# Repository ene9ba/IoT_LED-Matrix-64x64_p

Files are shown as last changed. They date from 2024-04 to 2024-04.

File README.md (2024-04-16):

# IoT_LED-Matrix-64x64_p
LED-Matrix Display driven by Raspi PICOW  Comchain: openHAB - mqtt - wifi - display develoed with platformio
**IoT RGB-Matrixdisplay to visualize temperatures from air ant HOT Tub via WiFi over MQTT to openHAB**
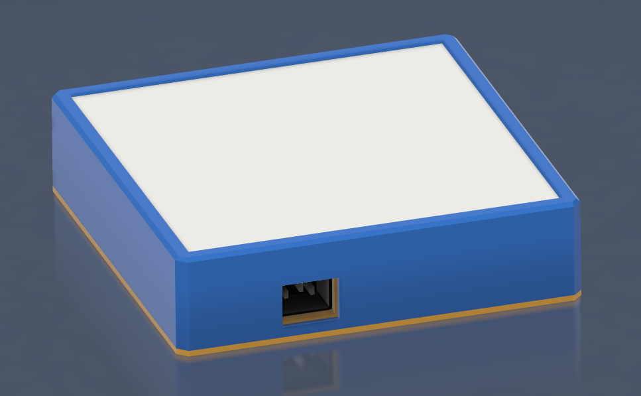
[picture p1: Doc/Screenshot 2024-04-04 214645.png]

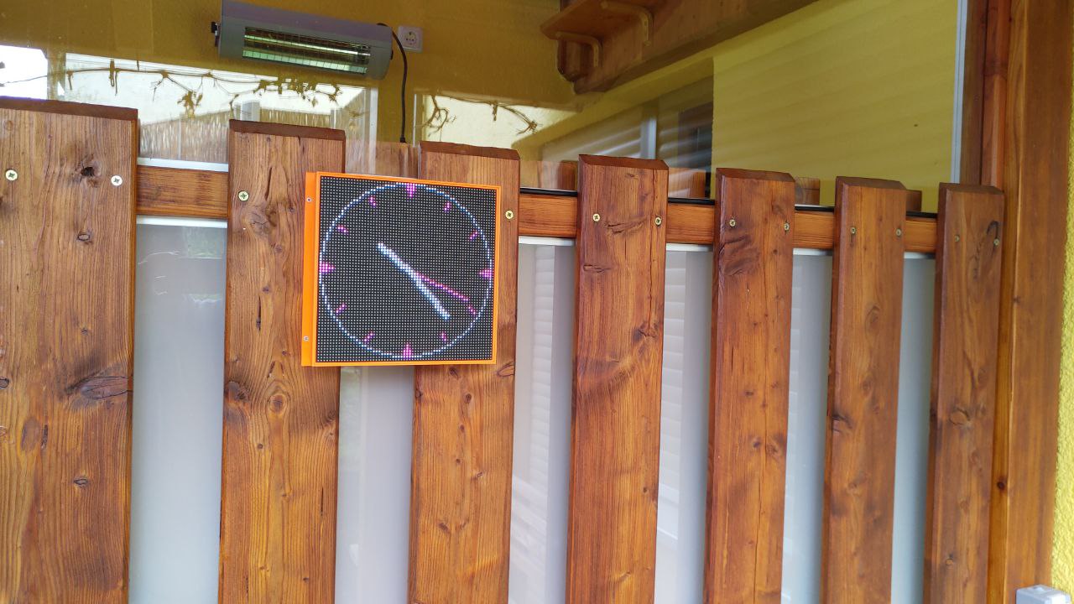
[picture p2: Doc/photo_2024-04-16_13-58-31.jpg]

# Goal of this project
To use a 64x64 RGB matrix display for visualisation of temperature, time and systemstate of my HotTub (whrilpool).
The picture should be absolute flickerree.

The project consits of three parts:

## Part 1: 
Hardwaredesign controller RP 2040 PICO W and powershifting 3.3 V to 5 V 
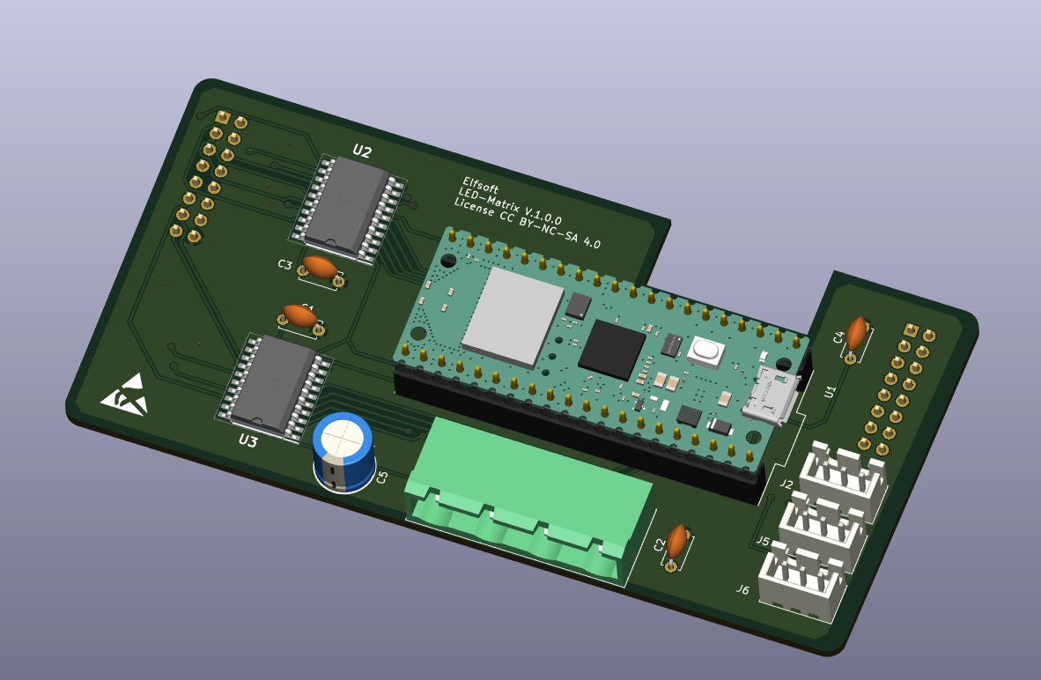
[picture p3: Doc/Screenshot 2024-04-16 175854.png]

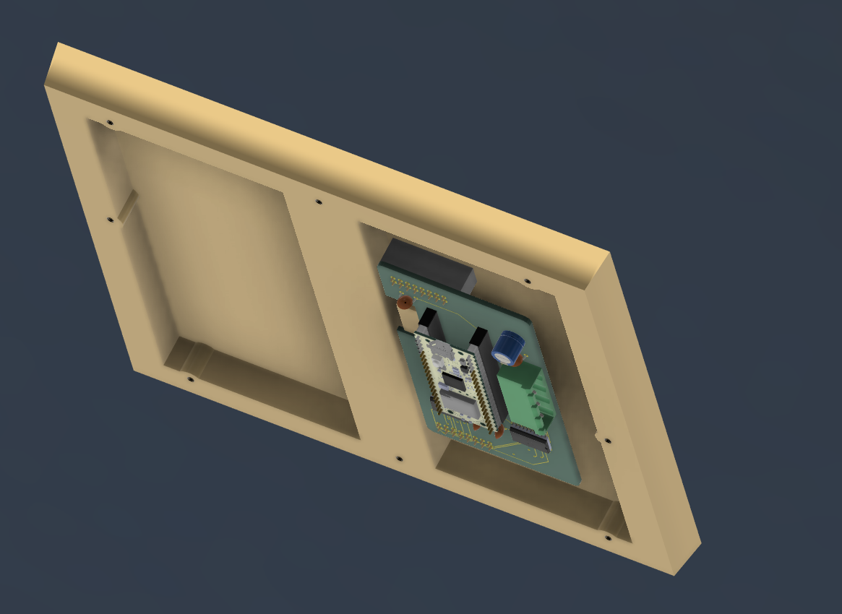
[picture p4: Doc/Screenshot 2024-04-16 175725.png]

## Part 2: 
Softwaredevelopment matrix control, connection to Wifi, connection to mqtt 

## Part 3: 3D Case design
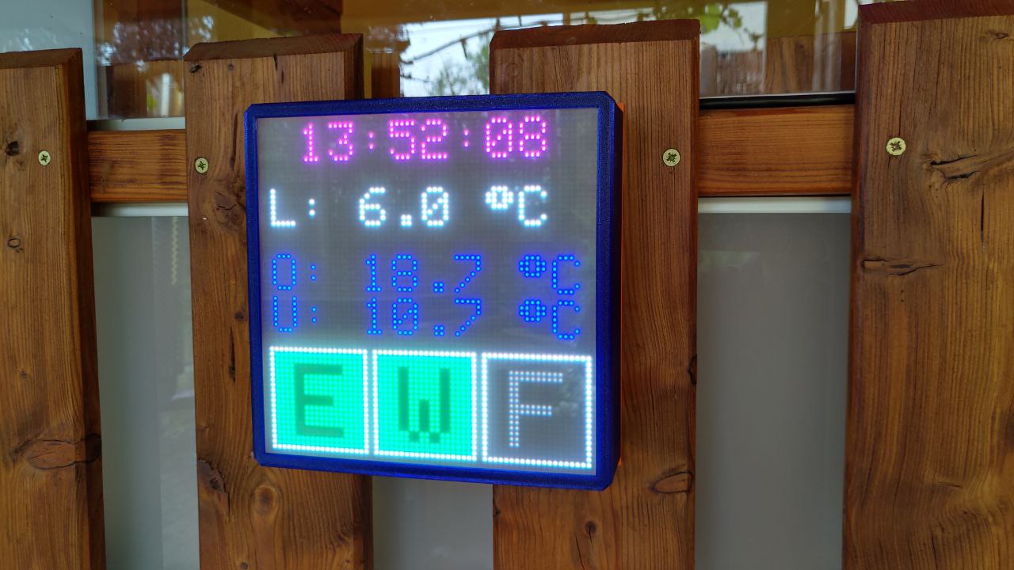
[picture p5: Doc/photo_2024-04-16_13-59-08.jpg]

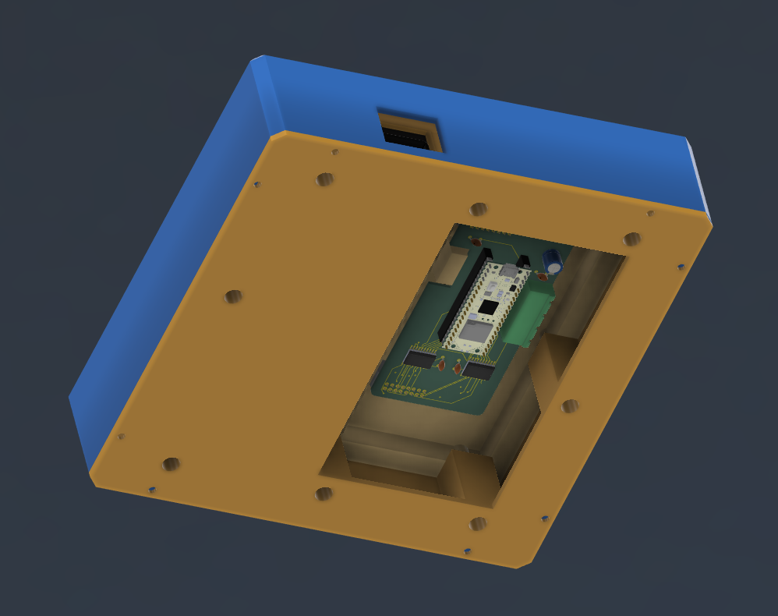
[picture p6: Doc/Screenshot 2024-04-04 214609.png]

## Info:
The LED-Panel is integrated in a self designed case with integrated power supply. Communication to SMART-Home runs via WiFi and MQTT to opnHAB.
The contoller I'm using is Raspberry Pi PICO RP2040 because it meets the requriements for WiFi and control the LED-panel **flickerfree** using the realtine state-machine on the chip.

The pcb will be pluged directly to the pins on the panel, there is no need for additional cabling.

Software ist developed with PlatformIO IDE.

I'm using displaytype RGB_LEF Joy-It. Most pinouts from other manaufactorers are the same, but have a look to the pcb pinout to be shure pining fits.

### Designfiles for the Case you can find on [thingeverese]() or [printables]().

### Credits and Acknowledgments
This project builds upon the work of the following contributors:

**pitschu:** For providing the initial groundwork and hardware interfacing for driving HUB75 LED Matrix panels with Raspberry Pi Pico's PIO

**Bodmer/Adafruit-GFX-Library:** For the core graphics library, enabling compatibility with Adafruit's GFX library and enhancing the display manipulation capabilities of the project.

**ClemensElflein:** For adapt the software to run on pico w without FREERTOS (works now with Arduino WifFi libraries)

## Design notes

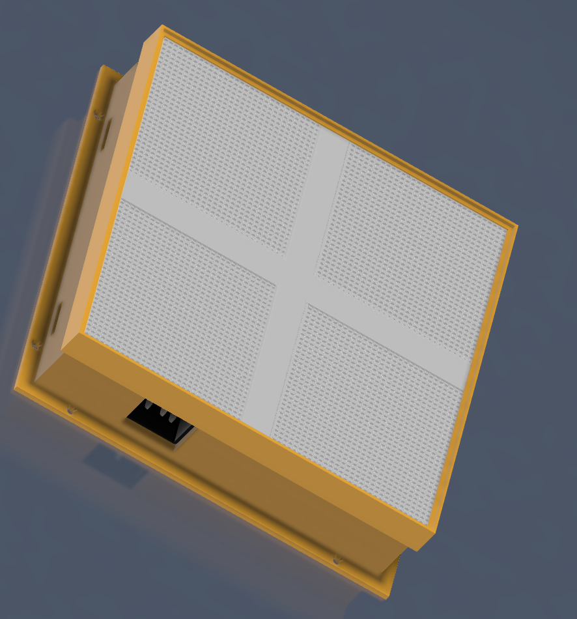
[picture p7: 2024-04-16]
Doc/Screenshot 2024-04-04 214305.png

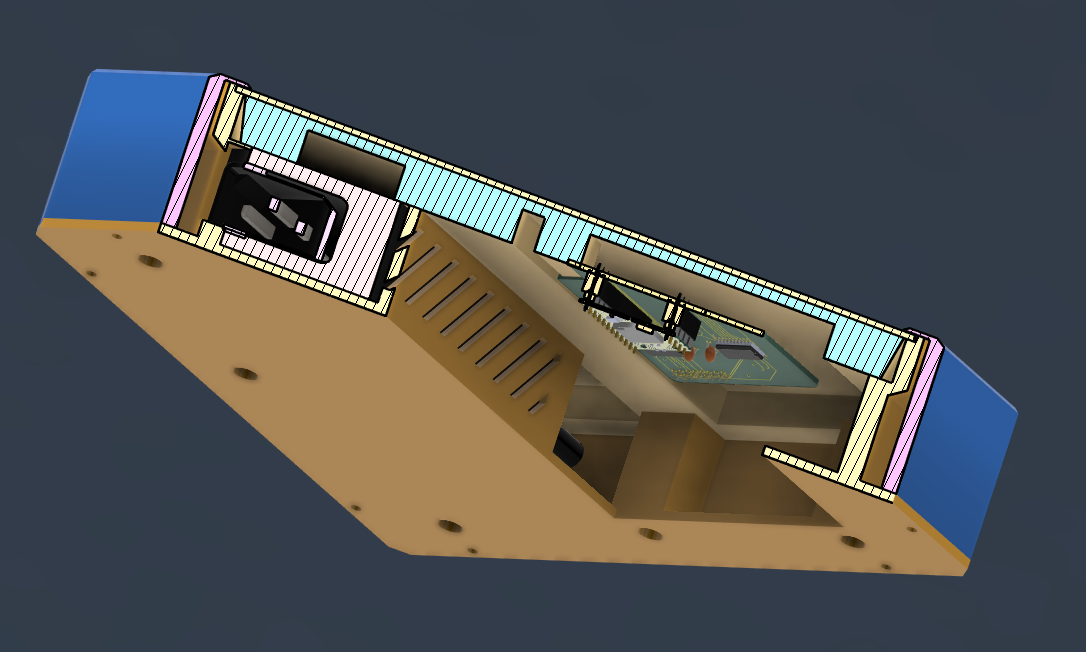
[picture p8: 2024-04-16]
Doc/Screenshot 2024-04-04 220111.png

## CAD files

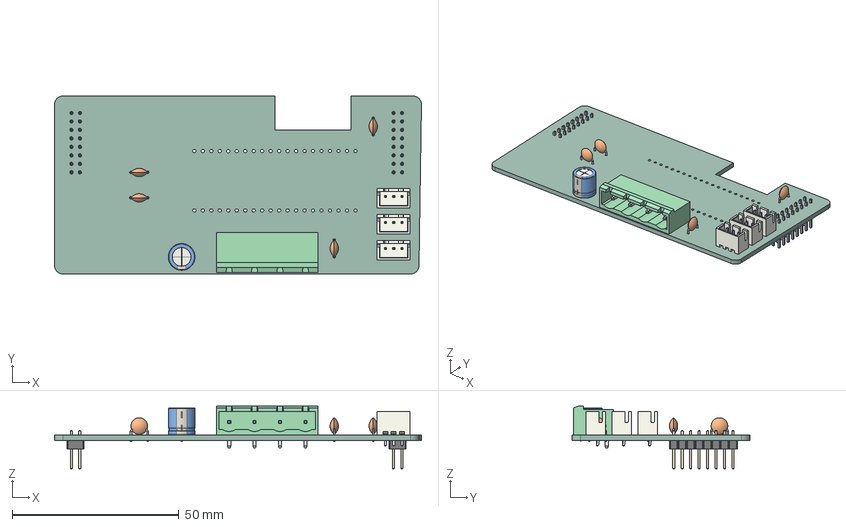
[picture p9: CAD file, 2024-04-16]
Hardware/LED-Matrix-driver.step
110.0 x 53.3 x 18.8 mm
C_Disc_D50mm_W25mm_P500mm x 4
GMSTBA_01x04_G_7_62mm
JST_B3B_XH_A x 3
CP_Radial_D80mm_P500mm
PinHeader_2x08_P254mm_Vertical x 2
_autosave-LED-Matrix-driver_PCB

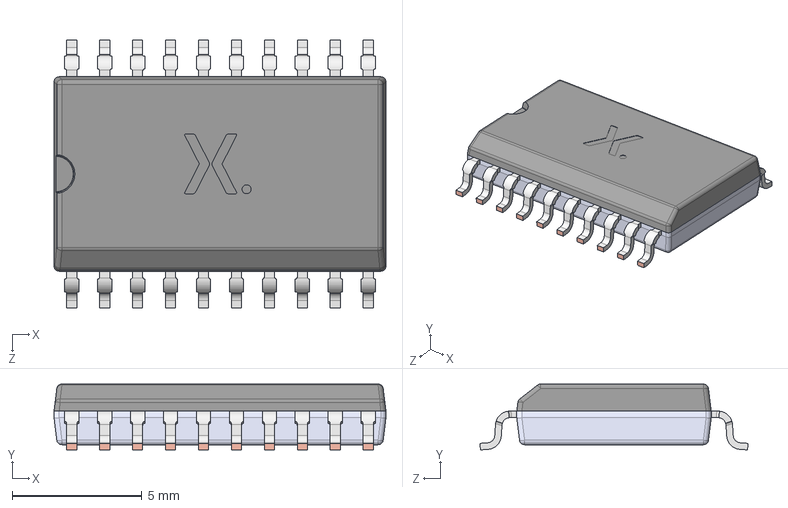
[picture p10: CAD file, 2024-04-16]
Hardware/3D/74HC245D-Q100J.stp
12.8 x 2.54 x 10.3 mm
SOT163 lower body
SOT163 upper body
SOT163-1 Lead

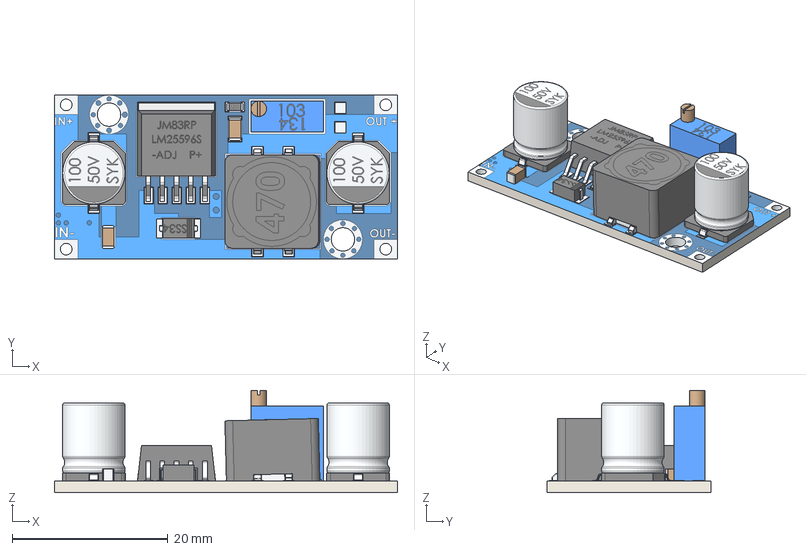
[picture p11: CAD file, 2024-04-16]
Hardware/3D/LM2596.step
44.0 x 21.0 x 13.1 mm

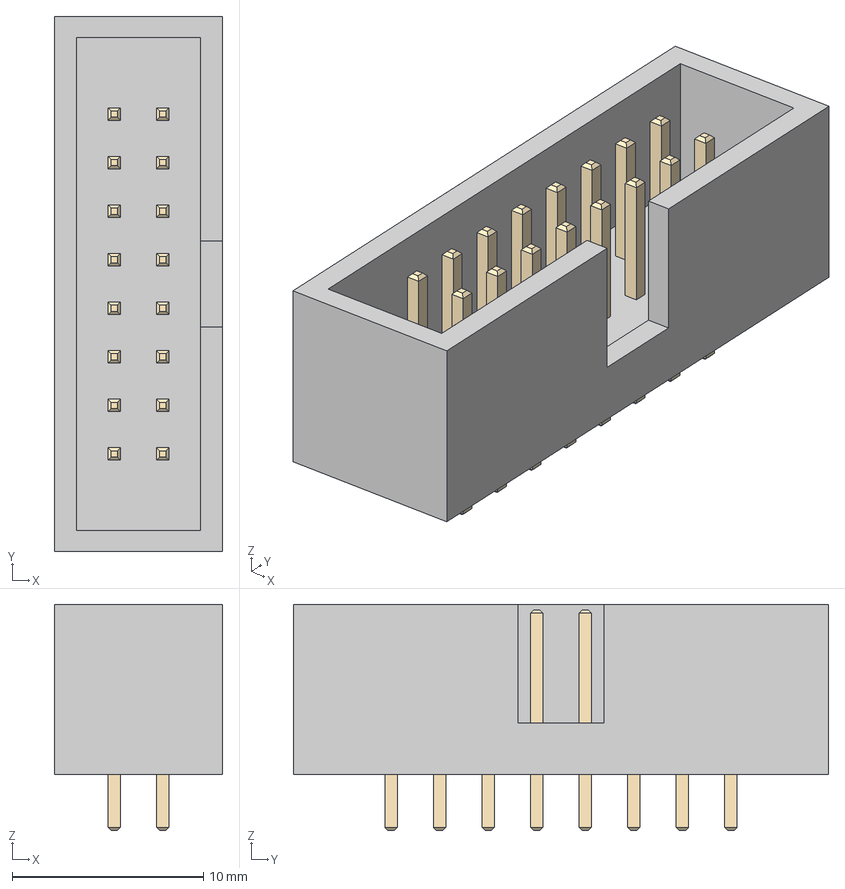
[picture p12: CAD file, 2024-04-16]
Hardware/3D/pinhead_2x8_shrouded.step
8.80 x 28.0 x 11.8 mm

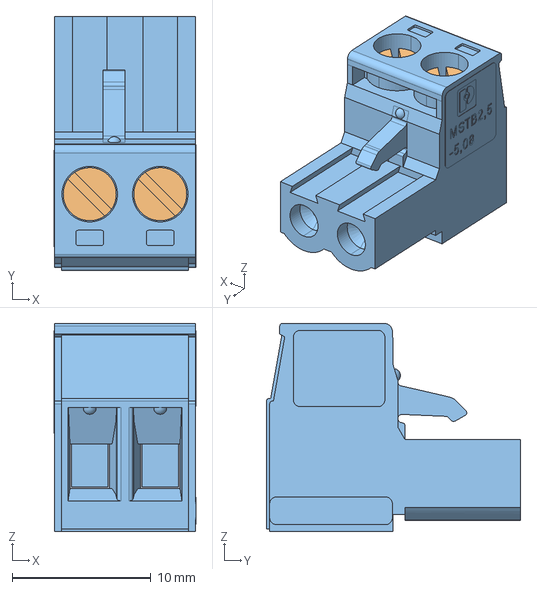
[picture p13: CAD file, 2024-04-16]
Hardware/3D/1757019.stp
10.2 x 18.3 x 15.0 mm

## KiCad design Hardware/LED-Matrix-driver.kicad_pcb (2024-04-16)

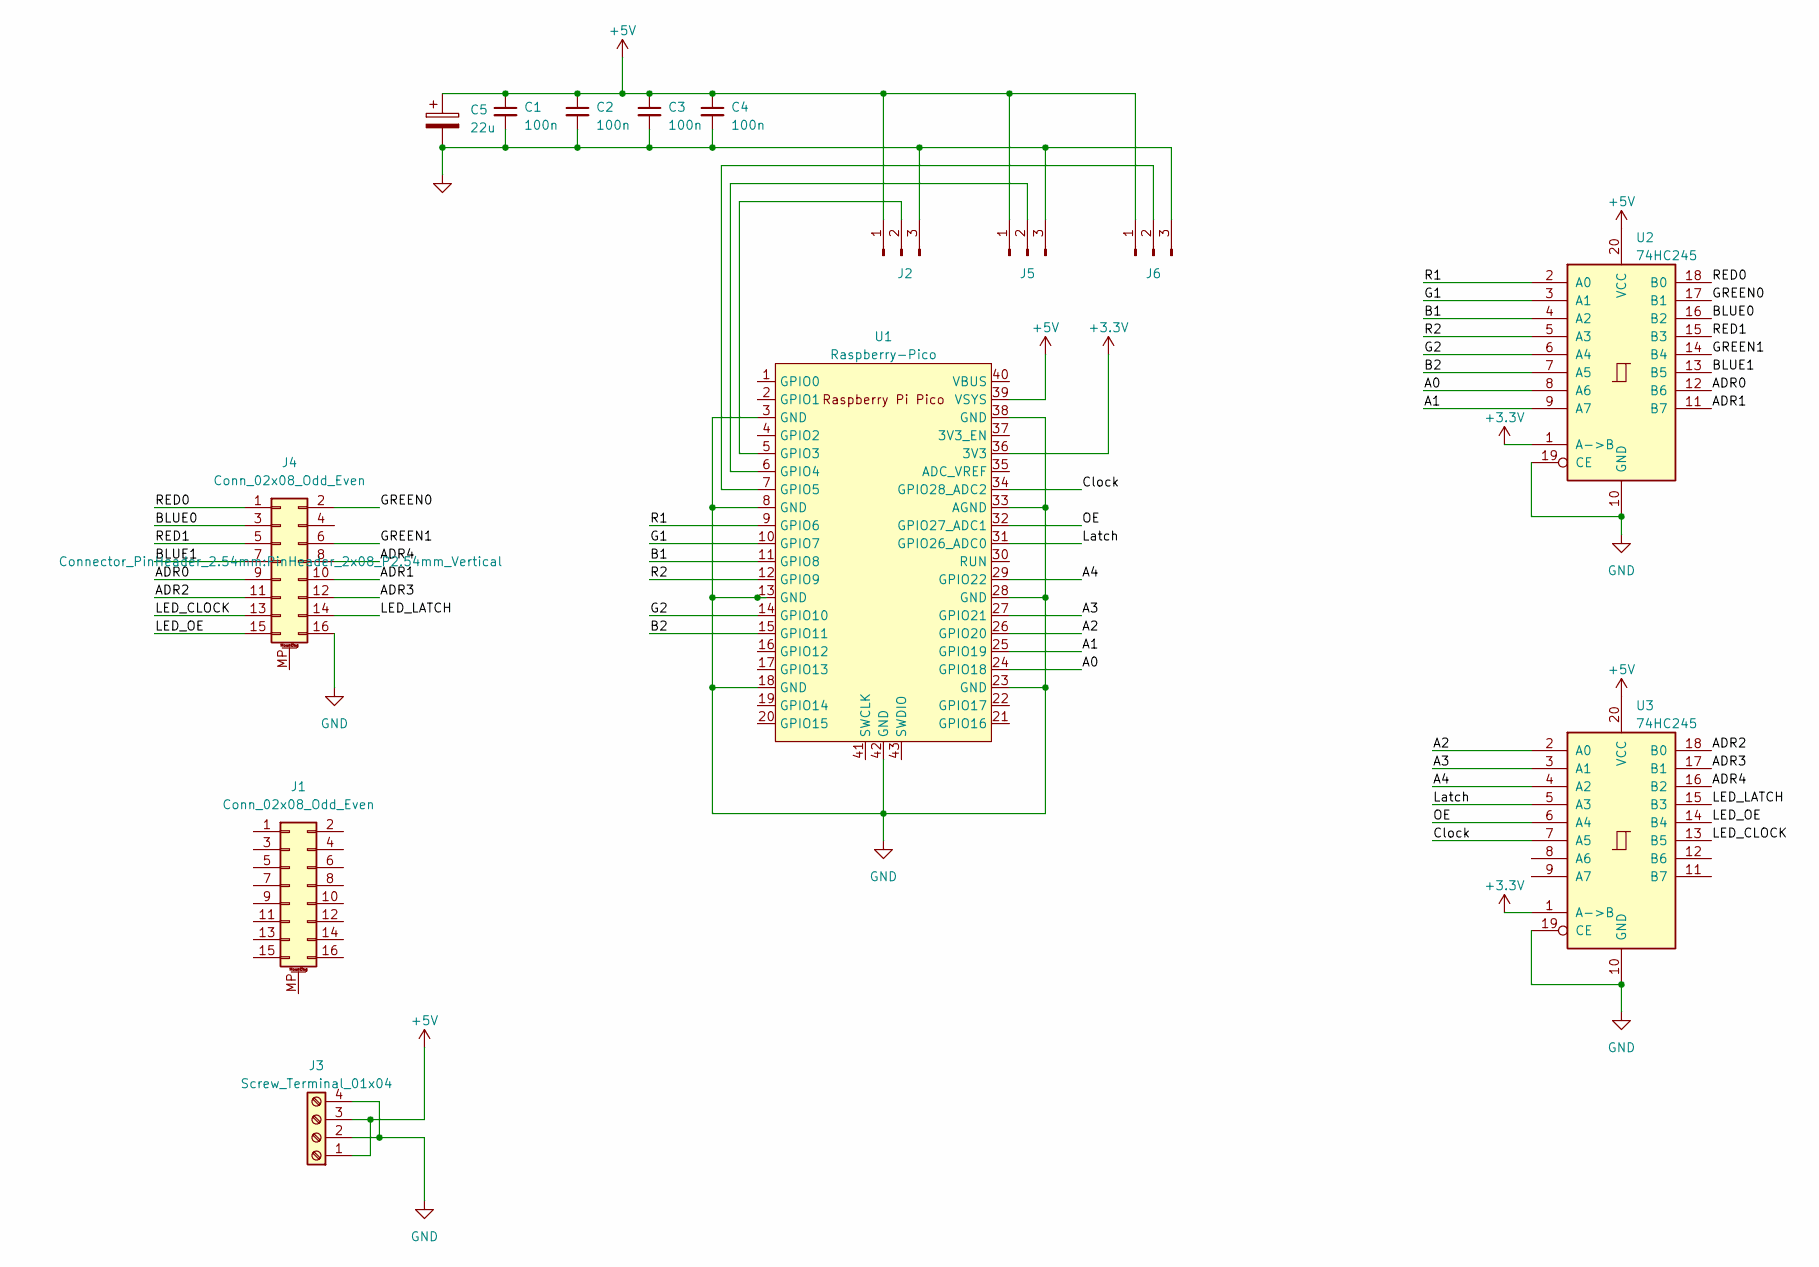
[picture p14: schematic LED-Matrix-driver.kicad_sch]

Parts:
C1, C2, C3, C4: 100n; C_Disc_D5.0mm_W2.5mm_P5.00mm
C5: 22u; CP_Radial_D8.0mm_P5.00mm
J1, J4: Conn_02x08_Odd_Even; PinHeader_2x08_P2.54mm_Vertical
J2, J5, J6: Conn_01x03_Pin; JST_XH_B3B-XH-A_1x03_P2.50mm_Vertical
J3: Screw_Terminal_01x04; PhoenixContact_GMSTBA_2,5_4-G-7,62_1x04_P7.62mm_Horizontal
U1: Raspberry-Pico; MODULE_SC0918
U2, U3: 74HC245; SOIC127P1032X265-20N

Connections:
+3.3V: U1.36 (3V3), U2.1 (A->B), U3.1 (A->B)
+5V: C1.1, C2.1, C3.1, C4.1, C5.1, J2.1, J3.1, J3.3, J5.1, J6.1, U1.39 (VSYS), U2.20 (VCC), U3.20 (VCC)
/A0: U1.24 (GPIO18), U2.8 (A6)
/A1: U1.25 (GPIO19), U2.9 (A7)
/A2: U1.26 (GPIO20), U3.2 (A0)
/A3: U1.27 (GPIO21), U3.3 (A1)
/A4: U1.29 (GPIO22), U3.4 (A2)
/ADR0: J4.9, U2.12 (B6)
/ADR1: J4.10, U2.11 (B7)
/ADR2: J4.11, U3.18 (B0)
/ADR3: J4.12, U3.17 (B1)
/ADR4: J4.8, U3.16 (B2)
/B1: U1.11 (GPIO8), U2.4 (A2)
/B2: U1.15 (GPIO11), U2.7 (A5)
/BLUE0: J4.3, U2.16 (B2)
/BLUE1: J4.7, U2.13 (B5)
/Clock: U1.34 (GPIO28_ADC2), U3.7 (A5)
/G1: U1.10 (GPIO7), U2.3 (A1)
/G2: U1.14 (GPIO10), U2.6 (A4)
/GREEN0: J4.2, U2.17 (B1)
/GREEN1: J4.6, U2.14 (B4)
/LED_CLOCK: J4.13, U3.13 (B5)
/LED_LATCH: J4.14, U3.15 (B3)
/LED_OE: J4.15, U3.14 (B4)
/Latch: U1.31 (GPIO26_ADC0), U3.5 (A3)
/OE: U1.32 (GPIO27_ADC1), U3.6 (A4)
/R1: U1.9 (GPIO6), U2.2 (A0)
/R2: U1.12 (GPIO9), U2.5 (A3)
/RED0: J4.1, U2.18 (B0)
/RED1: J4.5, U2.15 (B3)
GND: C1.2, C2.2, C3.2, C4.2, C5.2, J2.3, J3.2, J3.4, J4.16, J5.3, J6.3, U1.3 (GND), U1.8 (GND), U1.13 (GND), U1.18 (GND), U1.23 (GND), U1.28 (GND), U1.33 (AGND), U1.38 (GND), U1.42 (GND), U2.10 (GND), U2.19 (CE), U3.10 (GND), U3.19 (CE)
unnamed: J2.2, U1.5 (GPIO3)
unnamed: J5.2, U1.6 (GPIO4)
unnamed: J6.2, U1.7 (GPIO5)

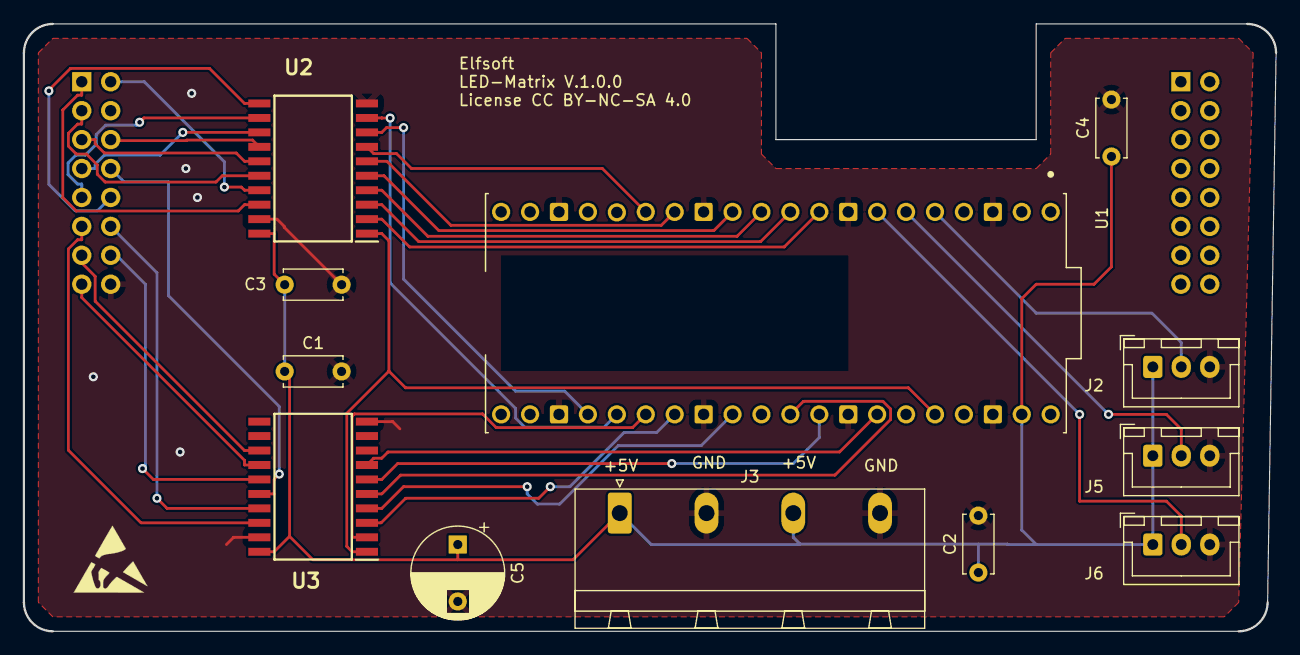
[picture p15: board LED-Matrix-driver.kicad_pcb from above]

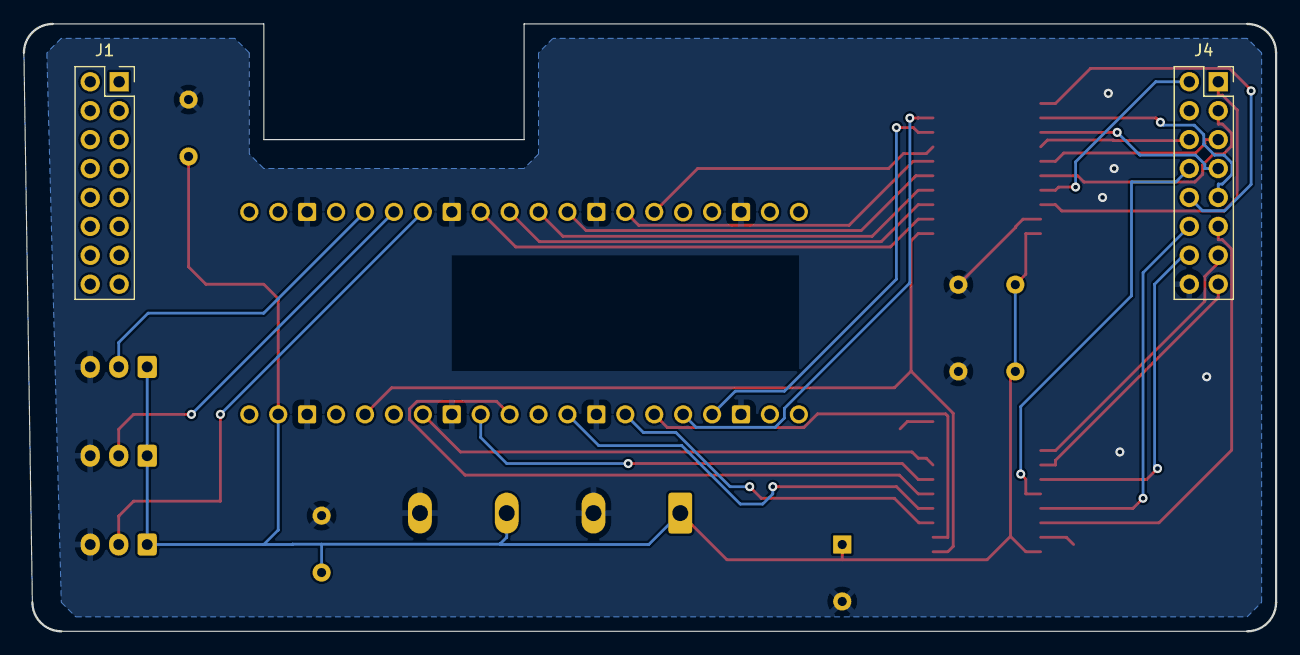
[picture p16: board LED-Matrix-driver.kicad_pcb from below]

Board: 2 copper layers, 110.0 x 53.3 mm, 15 parts (2 on the bottom side), 34 nets.

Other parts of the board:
LOGO2: ESD-Logo_6.6x6mm_SilkScreen

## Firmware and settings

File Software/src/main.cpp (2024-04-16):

// Version 1.1 v. 30.03.2024 Temperaturanzeige nur, wenn Energie ein
// Version 1.2 v. 02.04.2024 now with daylightsaving for the correct location, using RTC for timecount
// Version 1.3 v. 02.04.2024 correct text on display
// Version 1.4 v. 03.04.2024 char color changes while button pressed



// install pioasm
// https://gist.github.com/hexeguitar/f4533bc697c956ac1245b6843e2ef438
// install toolchain 
// https://arduino-pico.readthedocs.io/en/latest/platformio.html#examples

// DEGUGINFO
//#define __serial_DEBUG
#define __mqtt_DEBUG

#include <Arduino.h>

#include <CPU.h>


#include <GFXMatrix.h>
#include <WiFi.h>



#include <ArduinoOTA.h>
#include <PubSubClient.h>

// time stuff
#include <NTPClient.h>
#include <hardware/rtc.h>
#include <pico/util/datetime.h>

#include <watch.h>


#define SSI_ID  "your_SSID"
#define SSI_PWD "your_password"


WiFiUDP udpSocket;

#define NTP_SERVER1       "ptbtime1.ptb.de"
#define NTP_SERVER2       "europe.pool.ntp.org"
#define TIME_ZONE_BERLIN  "TZ","CET-1CEST,M3.5.0,M10.5.0/3"
// Define NTP Client to get time
NTPClient ntpClient(udpSocket, NTP_SERVER1);

WiFiClient espClient;
PubSubClient client(espClient);
GFXMatrix matrix(64, 64);
CPU cpu;
Watch my_Watch(&matrix);



#include <drawpicture.h>


const char* ssid = SSI_ID;
const char* password = SSI_PWD;
const char* mqtt_server = "VM2-MQTT";

#define MSG_BUFFER_SIZE	(100)
char msg[MSG_BUFFER_SIZE];
char dt[MSG_BUFFER_SIZE];



String Version    = "V1.40  ";
String AppName    = "IoT-LED-Matrix";

// mqtt publish values

const char* mqtt_pub_Val1             = "/openHAB/LED_Matrix/CPU_Temperature";
const char* mqtt_pub_RSSI             = "/openHAB/LED_Matrix/RSSI";
const char* mqtt_pub_Version          = "/openHAB/LED_Matrix/Version";
const char* mqtt_pub_Debug            = "/openHAB/LED_Matrix/Debug";
const char* mqtt_pub_lastconnect      = "/openHAB/LED_Matrix/lastReconnect";
const char* mqtt_pub_lastmsg          = "/openHAB/LED_Matrix/lastMessage";
const char* mqtt_pub_brightness       = "/openHAB/LED_Matrix/percentbrightness";

const char* mqtt_pub_energycontrol_c  = "/openHAB/gardenpower/switch/set_Power";                  // openhab command topic
const char* mqtt_pub_whirlcontrol_c   = "/openHAB/hot_tub_control/switch/set_power2";             // openhab command topic
const char* mqtt_pub_filtercontrol_c  = "/openHAB/hot_tub_control/switch/set_power1";             // openhab command topic

// mqtt subscribe values
const char* mqtt_sub_Val1         = "/openHAB/house/tempair";
const char* mqtt_sub_Val2         = "/openHAB/hot_tub_control/sensor/temperatur_vorlauf/state";
const char* mqtt_sub_Val3         = "/openHAB/hot_tub_control/sensor/temperatur_ruecklauf/state";
const char* mqtt_sub_Val4         = "/openHAB/hot_tub_control/switch/relay_output1/state";
const char* mqtt_sub_Val5         = "/openHAB/hot_tub_control/switch/relay_output2/state";
const char* mqtt_sub_Val6         = "/openHAB/gardenpower/switch/relay_output/state";
const char* mqtt_sub_Val7         = "/openHAB/house/brightness";


// IO
#define INPUT_BUTTON_FILTER 4   // IO GP4
#define INPUT_BUTTON_WHIRL  3   // IO GP3
#define INPUT_BUTTON_ENERGY 5   // IO GP5


#define POS_INFORECT_LI     1
#define POS_INFORECT_MI     22
#define POS_INFORECT_RE     43
#define ENERGY_CHAR         'E'
#define WHIRLPUMP_CHAR      'W'
#define FILTERPUMP_CHAR     'F'


// globals
float   cpu_temp        = 0.0f;   // temperature 2040 CPU
float   air_temp        = 0.0f;   // temperature air 
float   tub_temp_up     = 0.0f;   // temperature hot tub surface
float   tub_temp_down   = 0.0f;   // temperature hot tub bottom
int     rssi            = 0;      // field force 
int     env_brightness  = 0;      // brightness environment


String  filter          = "-";
String  whirl           = "-";
String  power           = "-";

u_int16_t second        = 0;
u_int16_t minute        = 0;
u_int16_t hour          = 0;

bool      switchdisplay = false;

#define   MAXCPUTEMP    50
bool      temp_error    = false;   // CPU-TEMP to high

int       percent_displaybrightness = 0;


uint      button_whirl_pump   = 0;
uint      button_energy       = 0;
uint      button_filter_pump  = 0;

time_t    systemtime          = 0;      // epoch time
struct tm *timeinfo;                    // cpp time

// time struct for RTC
datetime_t t = {
        .year  = 2120,
        .month = 06,
        .day   = 05,
        .dotw  = 1, // 0 is Sunday, so 5 is Friday
        .hour  = 0,
        .min   = 0,
        .sec   = 0
    };




#define   SCEDULE_SYSTEMVALUES 5000     // 5  seconds
#define   SCEDULE_TIME         1000     // 1  second
#define   SCEDULE_INFO         10000    // 10 seconds
#define   SCEDULE_WRITEOUT     1000     // 1  second
#define   SCEDULE_RR           120000   // 2 minutes
#define   SCEDULE_INPUT        100     //  0.1  second 

unsigned long thread_get_sysvalues  = 0;
unsigned long thread_get_time       = 0;
unsigned long thread_writeinfo      = 0;
unsigned long thread_writeout       = 0;
unsigned long thread_roundrobin     = 0;
unsigned long thread_readinput      = 0;

#define BLACK     0x0000
#define BLUE      0x001F
#define RED       0xF800
#define GREEN     0x07E0
#define CYAN      0x07FF
#define MAGENTA   0xF81F
#define YELLOW    0xFFE0
#define WHITE     0xFFFF
#define GRAY1     0x632c


#define RECT      20
#define DISPLAY_HEIGT 64

String HOSTNAME = "IoT-LEDMatrix";

#include <helpers.h>


void write_temperatures(bool force);


void get_sys_values() {

  long now = millis();
  if (now - thread_get_sysvalues < SCEDULE_SYSTEMVALUES) return;

  cpu_temp  =   cpu.getTemperature();
  rssi      =   WiFi.RSSI();

  if (cpu_temp > MAXCPUTEMP) temp_error = true; else temp_error = false;

  

  // publish rssi
  snprintf (msg, MSG_BUFFER_SIZE,"%d", rssi);
  client.publish(mqtt_pub_RSSI, msg);
  // publish Temperature
  snprintf (msg, MSG_BUFFER_SIZE,"%.1f", cpu_temp);
  client.publish(mqtt_pub_Val1, msg);
  
  client.publish(mqtt_pub_lastmsg,dt);

  snprintf (msg, MSG_BUFFER_SIZE,"%d", percent_displaybrightness);
  client.publish(mqtt_pub_brightness, msg);

  thread_get_sysvalues = now;

}

// switch between clock Page and temperatur page
void roundrobin() {

  long now = millis();
  if (now - thread_roundrobin < SCEDULE_RR ) return;
  
  switchdisplay = !switchdisplay;
  
  ntpClient.update();

  thread_roundrobin = now;

}





void get_time() {

  long now = millis();
  if (now - thread_get_time < SCEDULE_TIME) return;

  rtc_get_datetime(&t);
  hour = t.hour;
  minute = t.min;
  second = t.sec;

 
  //calculate brightness depend on Openhab value 0 - 5000 equal to 10% to 80 %  
  if(env_brightness < 0 || env_brightness > 5000 ) env_brightness = 0;
  #define MAX_BRIGHTNESS 5000
  // calculate percent brightness of the current time of day
  int br_percent  = (int)(100.0f * env_brightness / MAX_BRIGHTNESS) ;  

  //snprintf(msg,MSG_BUFFER_SIZE,"ist Helligkeit %% %d",br_percent);
  //DebugInfo(msg);


  percent_displaybrightness = (int)(0.8f * br_percent + 20.0f);
  // if CPU temperature too high, set brigtness to 10 % else like calculated
  if (temp_error) percent_displaybrightness = 10; 

  //snprintf(msg,MSG_BUFFER_SIZE,"set Helligkeit %d",percent_displaybrightness);
  //DebugInfo(msg);

  matrix.setBrightness(percent_displaybrightness);
  

  thread_get_time = now;

}

void inforect(int x, int y, int w, uint16_t bkcolor, char mychar, uint16_t chrcolor) {

  matrix.drawRect(x, DISPLAY_HEIGT - w -1, w, w, WHITE);
  matrix.fillRect(x+1, DISPLAY_HEIGT - w , w-2, w-2, bkcolor);
  matrix.drawChar(x + 5, y +3, mychar, chrcolor, BLACK, 2);

}


void draw_clock() {

    long now = millis();
    if (now - thread_writeout < SCEDULE_WRITEOUT) return;
  
    
    matrix.setTextSize(1);
    matrix.clear();

    my_Watch.showtime(hour, minute, second);
    
    matrix.display();

  thread_writeout = now;

}


void get_inputs() {

    long now = millis();
    if (now - thread_readinput< SCEDULE_INPUT) return;
  

    digitalWrite(LED_BUILTIN, !digitalRead(LED_BUILTIN));

    button_energy =       digitalRead(INPUT_BUTTON_ENERGY);
    button_whirl_pump =   digitalRead(INPUT_BUTTON_WHIRL);
    button_filter_pump =  digitalRead(INPUT_BUTTON_FILTER);
    
    
    //Serial.print("Energy : "); Serial.println(button_energy);
    //Serial.print("whirl : "); Serial.println(button_whirl_pump);
    //Serial.print("filter : "); Serial.println(button_filter_pump);


    // toggle energy when button pressed

    if (button_energy == 1) {
      switchdisplay = false;
      write_temperatures(true);
      matrix.drawChar(POS_INFORECT_LI + 5, DISPLAY_HEIGT - RECT +2, ENERGY_CHAR, YELLOW , BLACK, 2);
      matrix.display();
      if (power == "ON") {
        client.publish(mqtt_pub_energycontrol_c, "OFF"); 
      
      }  
      else {
        client.publish(mqtt_pub_energycontrol_c, "ON"); 
      }
      while (digitalRead(INPUT_BUTTON_ENERGY) == 1);     
      matrix.drawChar(POS_INFORECT_LI + 5, DISPLAY_HEIGT - RECT +2, ENERGY_CHAR, GRAY1 , BLACK, 2);
      matrix.display();

    }  

    if (button_whirl_pump == 1) {
      switchdisplay = false;
      write_temperatures(true);
      matrix.drawChar(POS_INFORECT_MI + 5, DISPLAY_HEIGT - RECT +2, WHIRLPUMP_CHAR, YELLOW , BLACK, 2);
      matrix.display();
      if (whirl == "ON") {
        client.publish(mqtt_pub_whirlcontrol_c, "OFF"); 
      
      }  
      else {
        client.publish(mqtt_pub_whirlcontrol_c, "ON"); 
           
      }
      while (digitalRead(INPUT_BUTTON_WHIRL) == 1);     
      matrix.drawChar(POS_INFORECT_MI + 5, DISPLAY_HEIGT - RECT +2, WHIRLPUMP_CHAR, GRAY1 , BLACK, 2);
      matrix.display();

    }  


    if (button_filter_pump == 1) {
      switchdisplay = false;
      write_temperatures(true);
      matrix.drawChar(POS_INFORECT_RE + 5, DISPLAY_HEIGT - RECT +2, FILTERPUMP_CHAR, YELLOW , BLACK, 2);
      matrix.display();
      if (filter == "ON") {
        client.publish(mqtt_pub_filtercontrol_c, "OFF"); 
      
      }  
      else {
        client.publish(mqtt_pub_filtercontrol_c, "ON"); 
     
      }
      while (digitalRead(INPUT_BUTTON_FILTER) == 1);
      matrix.drawChar(POS_INFORECT_RE + 5, DISPLAY_HEIGT - RECT +2, FILTERPUMP_CHAR, GRAY1 , BLACK, 2);     
      matrix.display();

    }  
  
  thread_readinput = now;

}






void write_temperatures(bool force) {

  long now = millis();  
  if (!force) if (now - thread_writeout < SCEDULE_WRITEOUT) return;
  
  
  #define CHAR_HEIGHT   8
  #define XPOS          2

  int ypos = 1;
   

  matrix.setTextSize(1);
  matrix.clear();

  // write out current time
  matrix.setCursor(8,ypos);

  matrix.setTextColor(MAGENTA);
  snprintf(dt,MSG_BUFFER_SIZE,"%02d:%02d:%02d\n",hour,minute,second);
   
  matrix.println(dt);
  
  // write out Temperature air
  ypos+= CHAR_HEIGHT+4;
  matrix.setCursor(XPOS,ypos);
  matrix.setTextColor(WHITE);
  snprintf(msg,MSG_BUFFER_SIZE,"L: %.1f ",air_temp); 
  matrix.print(msg);  matrix.write(0xF8);  matrix.write(0x43); 

  // write out Temperature up

  ypos+= CHAR_HEIGHT+4;
  matrix.setCursor(XPOS,ypos);
  if (tub_temp_up <= 29) matrix.setTextColor(BLUE);
    else if ((tub_temp_up > 29) && (tub_temp_up <=32)) matrix.setTextColor(MAGENTA);
      else if ((tub_temp_up > 32) && (tub_temp_up <=34)) matrix.setTextColor(YELLOW);
        else if ((tub_temp_up > 34) && (tub_temp_up <=36)) matrix.setTextColor(GREEN);
          else if (tub_temp_up > 36) matrix.setTextColor(RED);
  if (power == "ON") snprintf(msg,MSG_BUFFER_SIZE,"O: %.1f ",tub_temp_up); else snprintf(msg,MSG_BUFFER_SIZE,"O: ---- ");        
  matrix.print(msg);  matrix.write(0xF8);  matrix.write(0x43);

  // write out Temperature down
  ypos+= CHAR_HEIGHT;
  matrix.setCursor(XPOS,ypos);
  if (tub_temp_down <= 29) matrix.setTextColor(BLUE);
    else if ((tub_temp_down > 29) && (tub_temp_down <=32)) matrix.setTextColor(MAGENTA);
      else if ((tub_temp_down > 32) && (tub_temp_down <=34)) matrix.setTextColor(YELLOW);
        else if ((tub_temp_down > 34) && (tub_temp_down <=36)) matrix.setTextColor(GREEN);
          else if (tub_temp_down > 36) matrix.setTextColor(RED);
  if (power == "ON") snprintf(msg,MSG_BUFFER_SIZE,"U: %.1f ",tub_temp_down); else snprintf(msg,MSG_BUFFER_SIZE,"U: ---- ");        
  matrix.print(msg);  matrix.write(0xF8);  matrix.write(0x43);


  // Power off / on
  if (power == "ON") inforect(POS_INFORECT_LI, DISPLAY_HEIGT - RECT -1, RECT, GREEN, ENERGY_CHAR, BLACK);
      else {
          inforect(1, DISPLAY_HEIGT - RECT -1, RECT, BLACK, ENERGY_CHAR, GRAY1);
          filter = "OFF";
          whirl = "OFF";
      }
      
  // Whirl off / on
  if (whirl == "ON") inforect(POS_INFORECT_MI, DISPLAY_HEIGT - RECT -1, RECT, GREEN, WHIRLPUMP_CHAR, BLACK);
      else inforect(22, DISPLAY_HEIGT - RECT -1, RECT, BLACK, WHIRLPUMP_CHAR,GRAY1);  

  // Filter off / on
  if (filter == "ON" ) inforect(POS_INFORECT_RE, DISPLAY_HEIGT - RECT -1, RECT, RED, FILTERPUMP_CHAR, BLACK);
      else inforect(43, DISPLAY_HEIGT - RECT -1, RECT, BLACK, FILTERPUMP_CHAR, GRAY1);

  // show error if cputemperature too high
  if (temp_error) matrix.drawChar(0, 0, 'T', RED, BLACK, 1);
    
  matrix.display();

  thread_writeout = now;

}



void write_info() {

long now = millis();
  if (now - thread_writeinfo < SCEDULE_INFO) return;
  
    snprintf(dt,MSG_BUFFER_SIZE," Time                    : %02d:%02d:%02d", hour, minute, second);
    DebugInfo(dt);    
    snprintf(msg,MSG_BUFFER_SIZE, "Temperatur Luft        : %.1f °C",air_temp);
    DebugInfo(msg);
    snprintf(msg,MSG_BUFFER_SIZE, "Helligkeit Umwelt      : %d" ,env_brightness);
    DebugInfo(msg);
    snprintf(msg,MSG_BUFFER_SIZE, "Temperatur HotTub Oben : %.1f °C",tub_temp_up);
    DebugInfo(msg);
    snprintf(msg,MSG_BUFFER_SIZE, "Temperatur HotTub Unten: %.1f °C",tub_temp_down);
    DebugInfo(msg);
    String myString =             "Schalter Filterpumpe   : " + filter;
    DebugInfo(myString);
    myString=                     "Schalter Whirlpumpe    : " + whirl;
    DebugInfo(myString);
    myString =                    "Schalter Strom für Pool: " + power;
    DebugInfo(myString);
    DebugInfo(                    "Temperatur CPU         : " + String(cpu_temp) + " °C");
    DebugInfo(                    "RSS                    : " + String(rssi) + " db");

  thread_writeinfo = now;



}







void setup() {
  

 
  //pinMode(LED_BUILTIN,OUTPUT);
  Serial.begin(19200);
  Serial.println("Booting");

  // init inputs
  pinMode(INPUT_BUTTON_ENERGY,INPUT); pinMode(INPUT_BUTTON_WHIRL,INPUT); pinMode(INPUT_BUTTON_FILTER,INPUT);
  pinMode(LED_BUILTIN,OUTPUT);

  matrix.begin();
  matrix.clear();
  matrix.cp437(true);
  matrix.setTextSize(1);
  matrix.setTextColor(GREEN);
  matrix.setCursor(0,0);
  matrix.println("booting");
  matrix.display();
  matrix.setCursor(0,8);
  matrix.println("WiFi");
  matrix.display();

  cpu.begin();  // Initialize the CPU temperature sensor
  
  attach_wifi();
  attach_mqtt();
  mqtt_subscribe();

  // set correct timezone Berlin daylightsaving
  setenv(TIME_ZONE_BERLIN,1),
  tzset();

  // setup ntp and RTC
  ntpClient.begin();
  ntpClient.update();
  systemtime = ntpClient.getEpochTime();
  timeinfo = localtime( &systemtime );
  // intit realtimeclock
  rtc_init(); 
  t.hour = timeinfo->tm_hour;
  t.min  = timeinfo->tm_min;
  t.sec  = timeinfo->tm_sec;
  rtc_set_datetime(&t);

  matrix.setCursor(0,16);
  matrix.println("MQTT");
  matrix.display();
  
  // publish version
  String out=Version+AppName;
  DebugInfo("Version: "+out);
  out.toCharArray(msg,75);
  client.publish(mqtt_pub_Version, msg);
  client.publish(mqtt_pub_lastconnect,dt);


  matrix.setCursor(0,24);
  matrix.println("V "+Version);
  matrix.display();
  delay(2000);

  init_OTA();

  matrix.clear();
  drawImage(0,0);
  matrix.display();

  delay(20000);

}



void loop() {
  
    roundrobin();

    if (!switchdisplay) write_temperatures(false); else draw_clock();
    //draw_clock();
    
    get_sys_values();

    get_time();

    write_info();

    if (!client.connected()) {
      reconnect();
    }
  
    client.loop();

    ArduinoOTA.handle();

    get_inputs();
    
  }

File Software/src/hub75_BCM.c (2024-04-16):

/*****************************************************
 *
 *	LED matrix driver for Raspberry RP2040
 *	(c) Peter Schulten, Mülheim, Germany
 *	peter_(at)_pitschu.de
 *
 *  Unmodified reproduction and distribution of this entire
 *  source code in any form is permitted provided the above
 *  notice is preserved.
 *  I make this source code available free of charge and therefore
 *  offer neither support nor guarantee for its functionality.
 *  Furthermore, I assume no liability for the consequences of
 *  its use.
 *  The source code may only be used and modified for private,
 *  non-commercial purposes. Any further use requires my consent.
 *
 *	History
 *	25.01.2022	pitschu		Start of work
 */
#include <stdio.h>
#include <string.h>
#include "stdint.h"
#include "stdlib.h"
#include "pico/stdlib.h"
#include "hardware/dma.h"
#include "hardware/irq.h"
#include "hub75.h"

#if HUB75_SIZE == 4040
uint32_t frameBuffer[DISPLAY_MAXPLANES * (DISPLAY_WIDTH / 4) * DISPLAY_SCAN]; // each entry contains RGB data for 2 or 4 consective pixels on one HUB75 channel
#elif HUB75_SIZE == 8080
uint32_t frameBuffer[DISPLAY_MAXPLANES * (DISPLAY_WIDTH / 2) * DISPLAY_SCAN]; // each entry contains RGB data for 2 pixels on two HUB75 channels
#else
    #error "V2 board supports 64x64 or 128x128 layouts"
#endif
rgb_t* addrBuffer[(1<<DISPLAY_MAXPLANES)];
uint16_t  bcmCounter = 1;     // index in addrBuffer array

uint32_t ctrlBuffer[DISPLAY_MAXPLANES * DISPLAY_SCAN]; // N bit planes * # of scan lines

uint16_t    masterBrightness = 0;
uint16_t    bitPlanes = DISPLAY_MAXPLANES;

static PIO display_pio = pio0;
static uint display_sm_data;
static uint display_offset_data;
static uint display_sm_ctrl;
static uint display_offset_ctrl;

static int display_dma_chan;
static int ctrl_dma_chan;

static rgb_t overlayColors[16];


static void dma_hub75_handler()
{
    // Clear the interrupt request.
    if (dma_hw->ints0 & (1u << display_dma_chan))
    {
        dma_hw->ints0 = 1u << display_dma_chan;
        // start next display cycle
        dma_channel_set_read_addr(display_dma_chan, addrBuffer[bcmCounter], true);
        if (++bcmCounter >= (1 << bitPlanes))
        {
            gpio_xor_mask(1<<15);       // debug LED for frame time measurement
            bcmCounter = 1;
        }
    }
    if (dma_hw->ints0 & (1u << ctrl_dma_chan))
    {
        dma_hw->ints0 = 1u << ctrl_dma_chan;
        // start next display cycle
        dma_channel_set_read_addr(ctrl_dma_chan, &ctrlBuffer[0], true);
    }
}


static void hub75_init() 
{
    // Initialize PIO
    display_sm_data = pio_claim_unused_sm(display_pio, true);
    display_sm_ctrl = pio_claim_unused_sm(display_pio, true);

#ifdef PCB_LAYOUT_V1
    display_offset_data = pio_add_program(display_pio, &ps_64_data_program);
    ps_64_data_program_init(
        display_pio,
        display_sm_data,
        display_offset_data,
        PIO_DATA_OUT_BASE, PIO_DATA_OUT_CNT,
        PIO_DATA_SET_BASE, PIO_DATA_SET_CNT,
        PIO_DATA_SIDE_BASE, PIO_DATA_SIDE_CNT
    );
 
    display_offset_ctrl = pio_add_program(display_pio, &ps_64_ctrl_program);
    ps_64_ctrl_program_init(
        display_pio,
        display_sm_ctrl,
        display_offset_ctrl,
        PIO_CTRL_OUT_BASE, PIO_CTRL_OUT_CNT,
        PIO_CTRL_SET_BASE, PIO_CTRL_SET_CNT,
        PIO_CTRL_SIDE_BASE, PIO_CTRL_SIDE_CNT
    );
#endif
#ifdef PCB_LAYOUT_V2
#if HUB75_SIZE == 4040
    display_offset_data = pio_add_program(display_pio, &ps_64_data_program);
    ps_64_data_program_init(
        display_pio,
        display_sm_data,
        display_offset_data,
        PIO_DATA_OUT_BASE, PIO_DATA_OUT_CNT,
        PIO_DATA_SET_BASE, PIO_DATA_SET_CNT,
        PIO_DATA_SIDE_BASE, PIO_DATA_SIDE_CNT
    );

    display_offset_ctrl = pio_add_program(display_pio, &ps_64_ctrl_program);
    ps_64_ctrl_program_init(
        display_pio,
        display_sm_ctrl,
        display_offset_ctrl,
        PIO_CTRL_OUT_BASE, PIO_CTRL_OUT_CNT,
        PIO_CTRL_SET_BASE, PIO_CTRL_SET_CNT,
        PIO_CTRL_SIDE_BASE, PIO_CTRL_SIDE_CNT
    );
#else
    display_offset_data = pio_add_program(display_pio, &ps_128_data_program);
    ps_128_data_program_init(
        display_pio,
        display_sm_data,
        display_offset_data,
        PIO_DATA_OUT_BASE, PIO_DATA_OUT_CNT,
        PIO_DATA_SET_BASE, PIO_DATA_SET_CNT,
        PIO_DATA_SIDE_BASE, PIO_DATA_SIDE_CNT
    );

    display_offset_ctrl = pio_add_program(display_pio, &ps_128_ctrl_program);
    ps_128_ctrl_program_init(
        display_pio,
        display_sm_ctrl,
        display_offset_ctrl,
        PIO_CTRL_OUT_BASE, PIO_CTRL_OUT_CNT,
        PIO_CTRL_SET_BASE, PIO_CTRL_SET_CNT,
        PIO_CTRL_SIDE_BASE, PIO_CTRL_SIDE_CNT
    );
#endif
#endif
    // ene9ba
    pio_sm_set_clkdiv(display_pio, display_sm_data, 2.0f);
    pio_sm_set_clkdiv(display_pio, display_sm_ctrl, 2.0f);
    // Initialize data port DMA
    display_dma_chan = dma_claim_unused_channel(true);
    dma_channel_config c = dma_channel_get_default_config(display_dma_chan);
    channel_config_set_transfer_data_size(&c, DMA_SIZE_32);
    channel_config_set_read_increment(&c, true);
    channel_config_set_write_increment(&c, false);
    channel_config_set_dreq(&c, DREQ_PIO0_TX0 + display_sm_data);

    //    channel_config_set_ring(&c, false, 15);     // ring size is 8192

    dma_channel_configure(
        display_dma_chan,
        &c,
        &pio0_hw->txf[display_sm_data],
        NULL,  // Will be set later for each transfer
#if HUB75_SIZE == 4040
        DISPLAY_SCAN * ((DISPLAY_WIDTH / 4)),     // complete frame buffer for 1 bit plane
#elif HUB75_SIZE == 8080
        DISPLAY_SCAN* ((DISPLAY_WIDTH / 2)),     // complete frame buffer for 1 bit plane
#endif
        false
    );
    dma_channel_set_irq0_enabled(display_dma_chan, true);

    // Initialize control port DMA
    ctrl_dma_chan = dma_claim_unused_channel(true);
    c = dma_channel_get_default_config(ctrl_dma_chan);
    channel_config_set_transfer_data_size(&c, DMA_SIZE_32);
    channel_config_set_read_increment(&c, true);
    channel_config_set_write_increment(&c, false);
    channel_config_set_dreq(&c, DREQ_PIO0_TX0 + display_sm_ctrl);

    dma_channel_configure(
        ctrl_dma_chan,
        &c,
        &pio0_hw->txf[display_sm_ctrl],
        NULL,  // Will be set later for each transfer
        DISPLAY_SCAN,     // complete frame buffer for 1 bit plane
        false
    );
    dma_channel_set_irq0_enabled(ctrl_dma_chan, true);

    irq_set_exclusive_handler(DMA_IRQ_0, dma_hub75_handler);
    irq_set_priority(DMA_IRQ_0, 1);
    irq_set_enabled(DMA_IRQ_0, true);
}



static void hub75_start()
{
    dma_channel_set_read_addr(display_dma_chan, frameBuffer, true);
    dma_channel_set_read_addr(ctrl_dma_chan, ctrlBuffer, true);
}
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

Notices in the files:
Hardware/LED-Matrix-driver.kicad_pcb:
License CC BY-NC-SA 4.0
